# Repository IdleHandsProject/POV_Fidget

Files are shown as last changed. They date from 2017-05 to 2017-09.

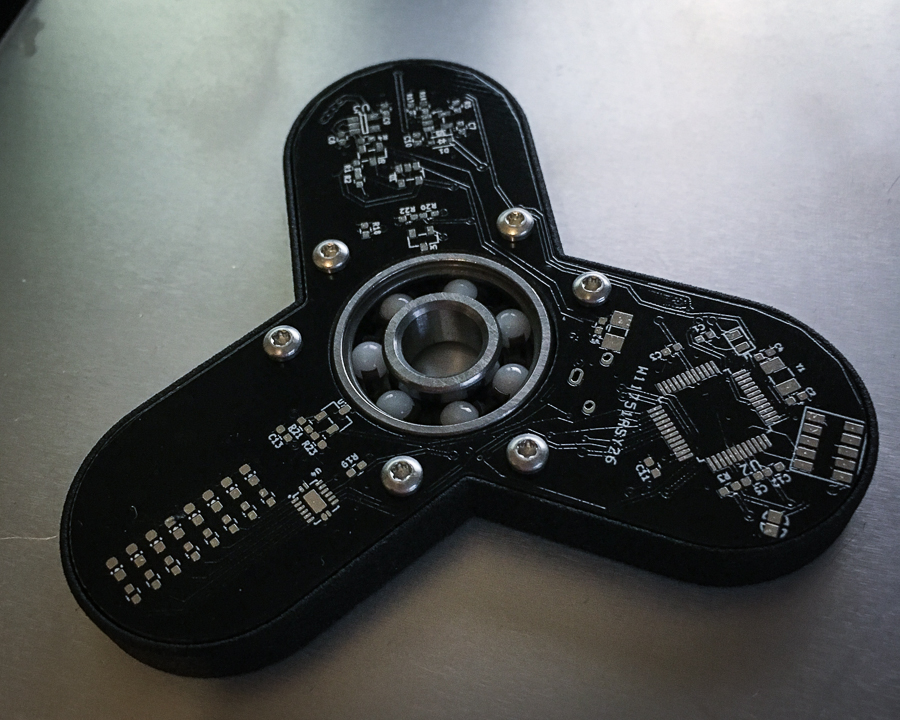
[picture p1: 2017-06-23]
MEDIA/Photo 2017-06-06, 8 44 38 PM.jpg

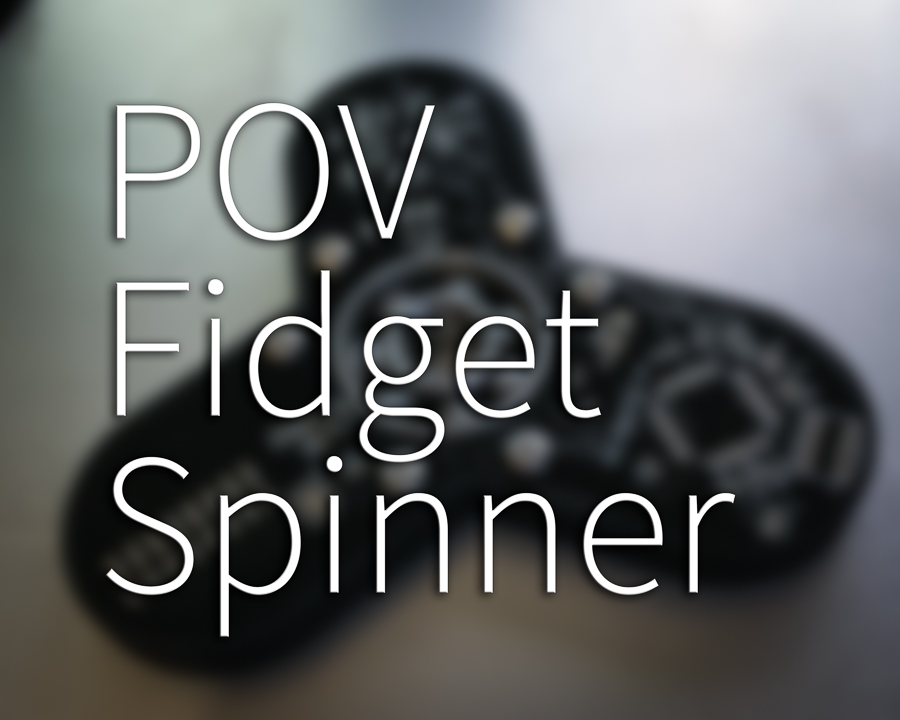
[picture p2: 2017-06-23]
MEDIA/Photo 2017-06-06, 8 44 38 PM-Edit-2.jpg

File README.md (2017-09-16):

# POV Arduino Fidget Spinner!

A lot of the info is in the video, check it out(Click the Image)!

DIY Arduino Fidget Spinner Video (http://www.youtube.com/watch?v=quEMfbOoROQ "Arduino POV Fidget Spinner")

Some more useful links:

https://hackaday.io/project/25538-pov-fidget-spinner

https://www.instructables.com/id/POV-Arduino-Fidget-Spinner/

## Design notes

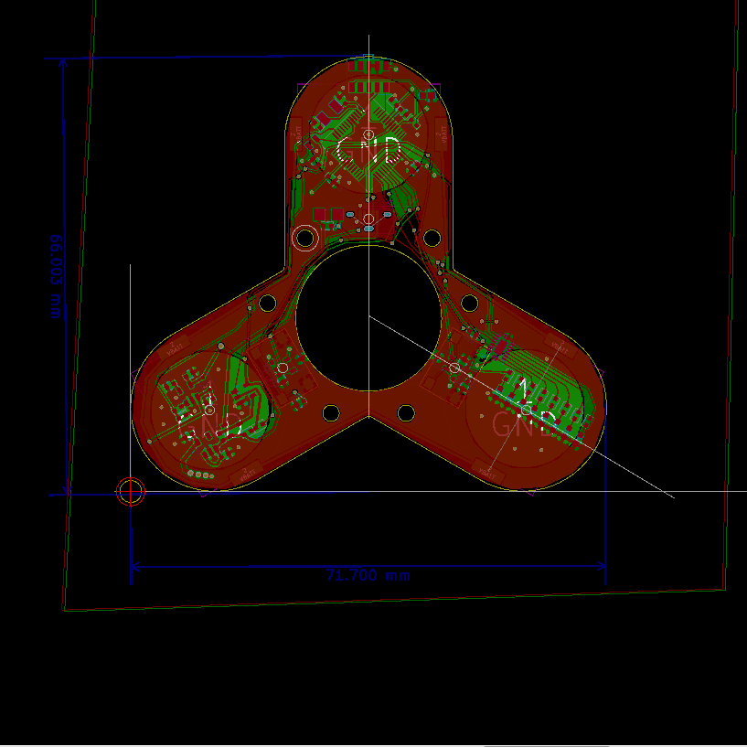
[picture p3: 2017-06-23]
MEDIA/Schem.png

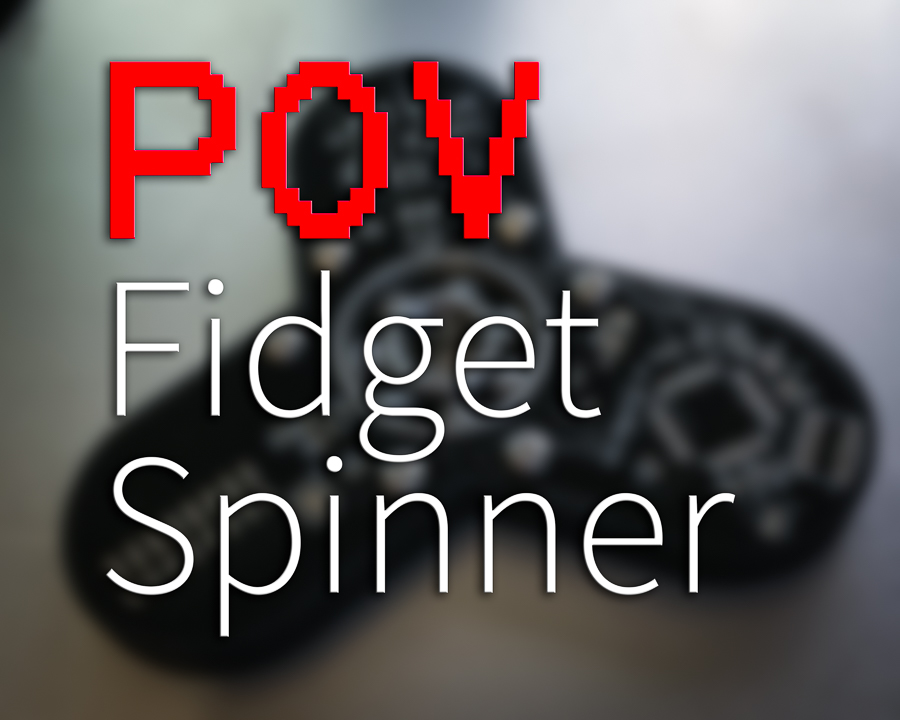
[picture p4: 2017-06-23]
MEDIA/Photo 2017-06-06, 8 44 38 PM-Edit.jpg

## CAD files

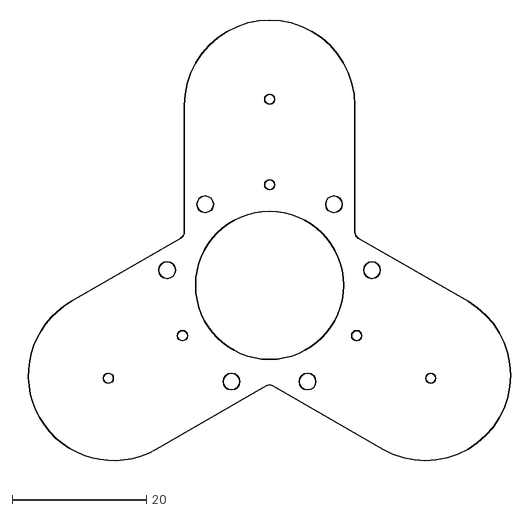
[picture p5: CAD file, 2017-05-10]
CAD/DXF/Body.dxf
73.8 x 68.1

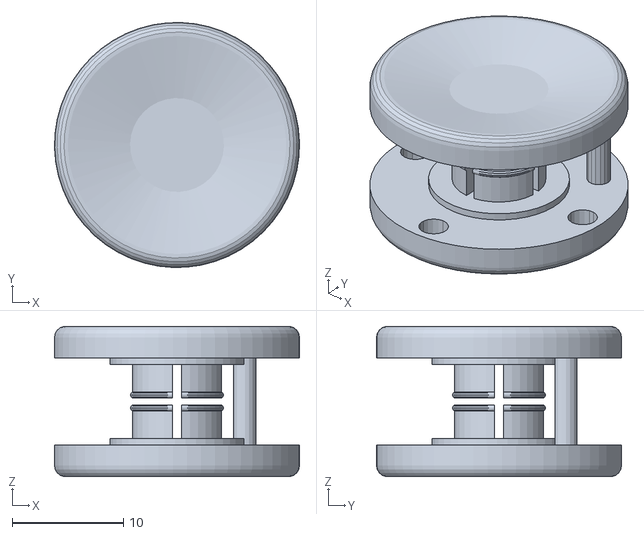
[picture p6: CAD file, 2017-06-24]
CAD/STL/22mm_Cap_Magnet_PairSprue.stl
22.0 x 22.0 x 13.5

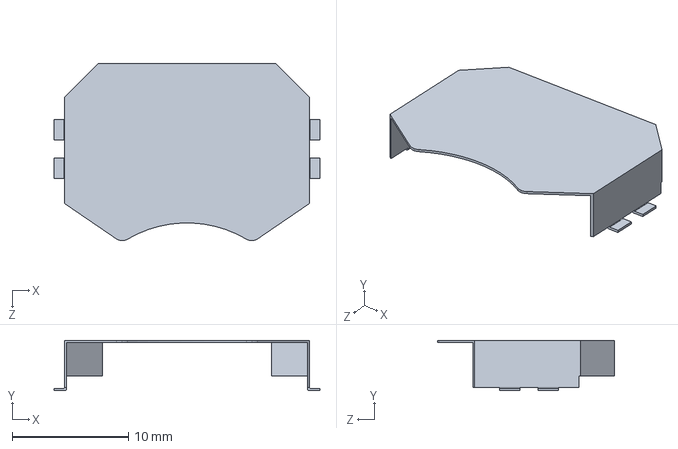
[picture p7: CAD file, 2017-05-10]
CAD/BK-912.STEP
22.9 x 4.32 x 15.2 mm

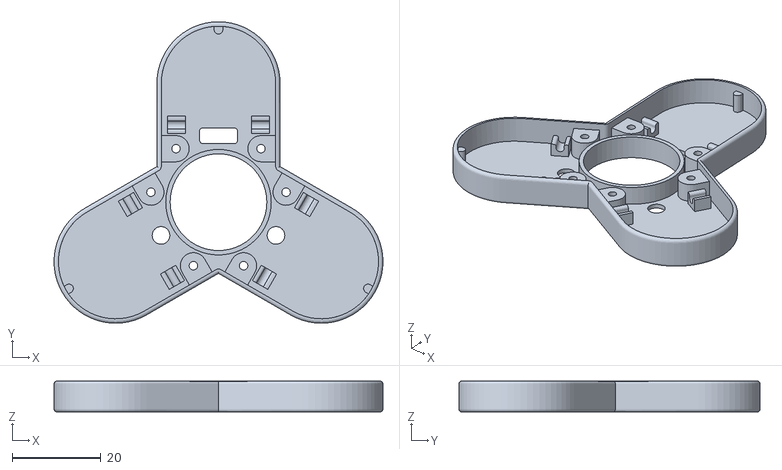
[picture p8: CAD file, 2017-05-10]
CAD/STL/Body_TriSpinArduino.stl
74.4 x 68.1 x 7.00

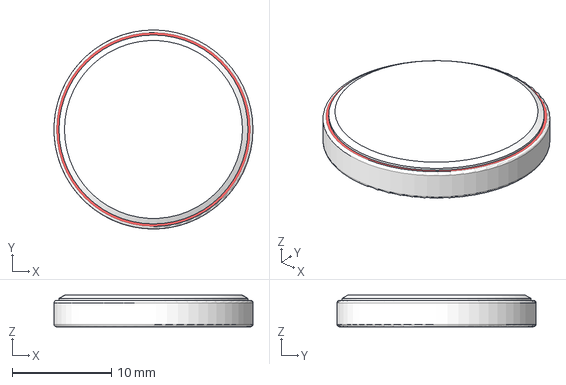
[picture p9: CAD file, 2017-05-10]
CAD/Battery CR2032.stp
20.0 x 20.0 x 3.18 mm

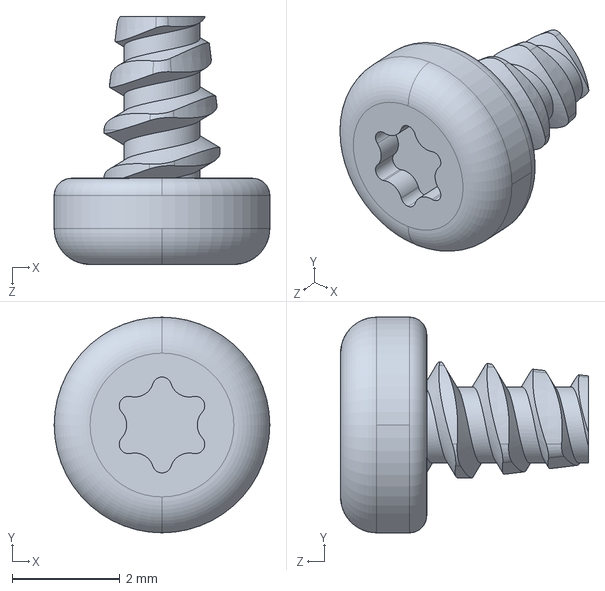
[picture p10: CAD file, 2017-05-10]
CAD/99397A321_METRIC THREAD-FORMING SCREW FOR PLASTICS.STEP
4.00 x 4.00 x 4.60 mm

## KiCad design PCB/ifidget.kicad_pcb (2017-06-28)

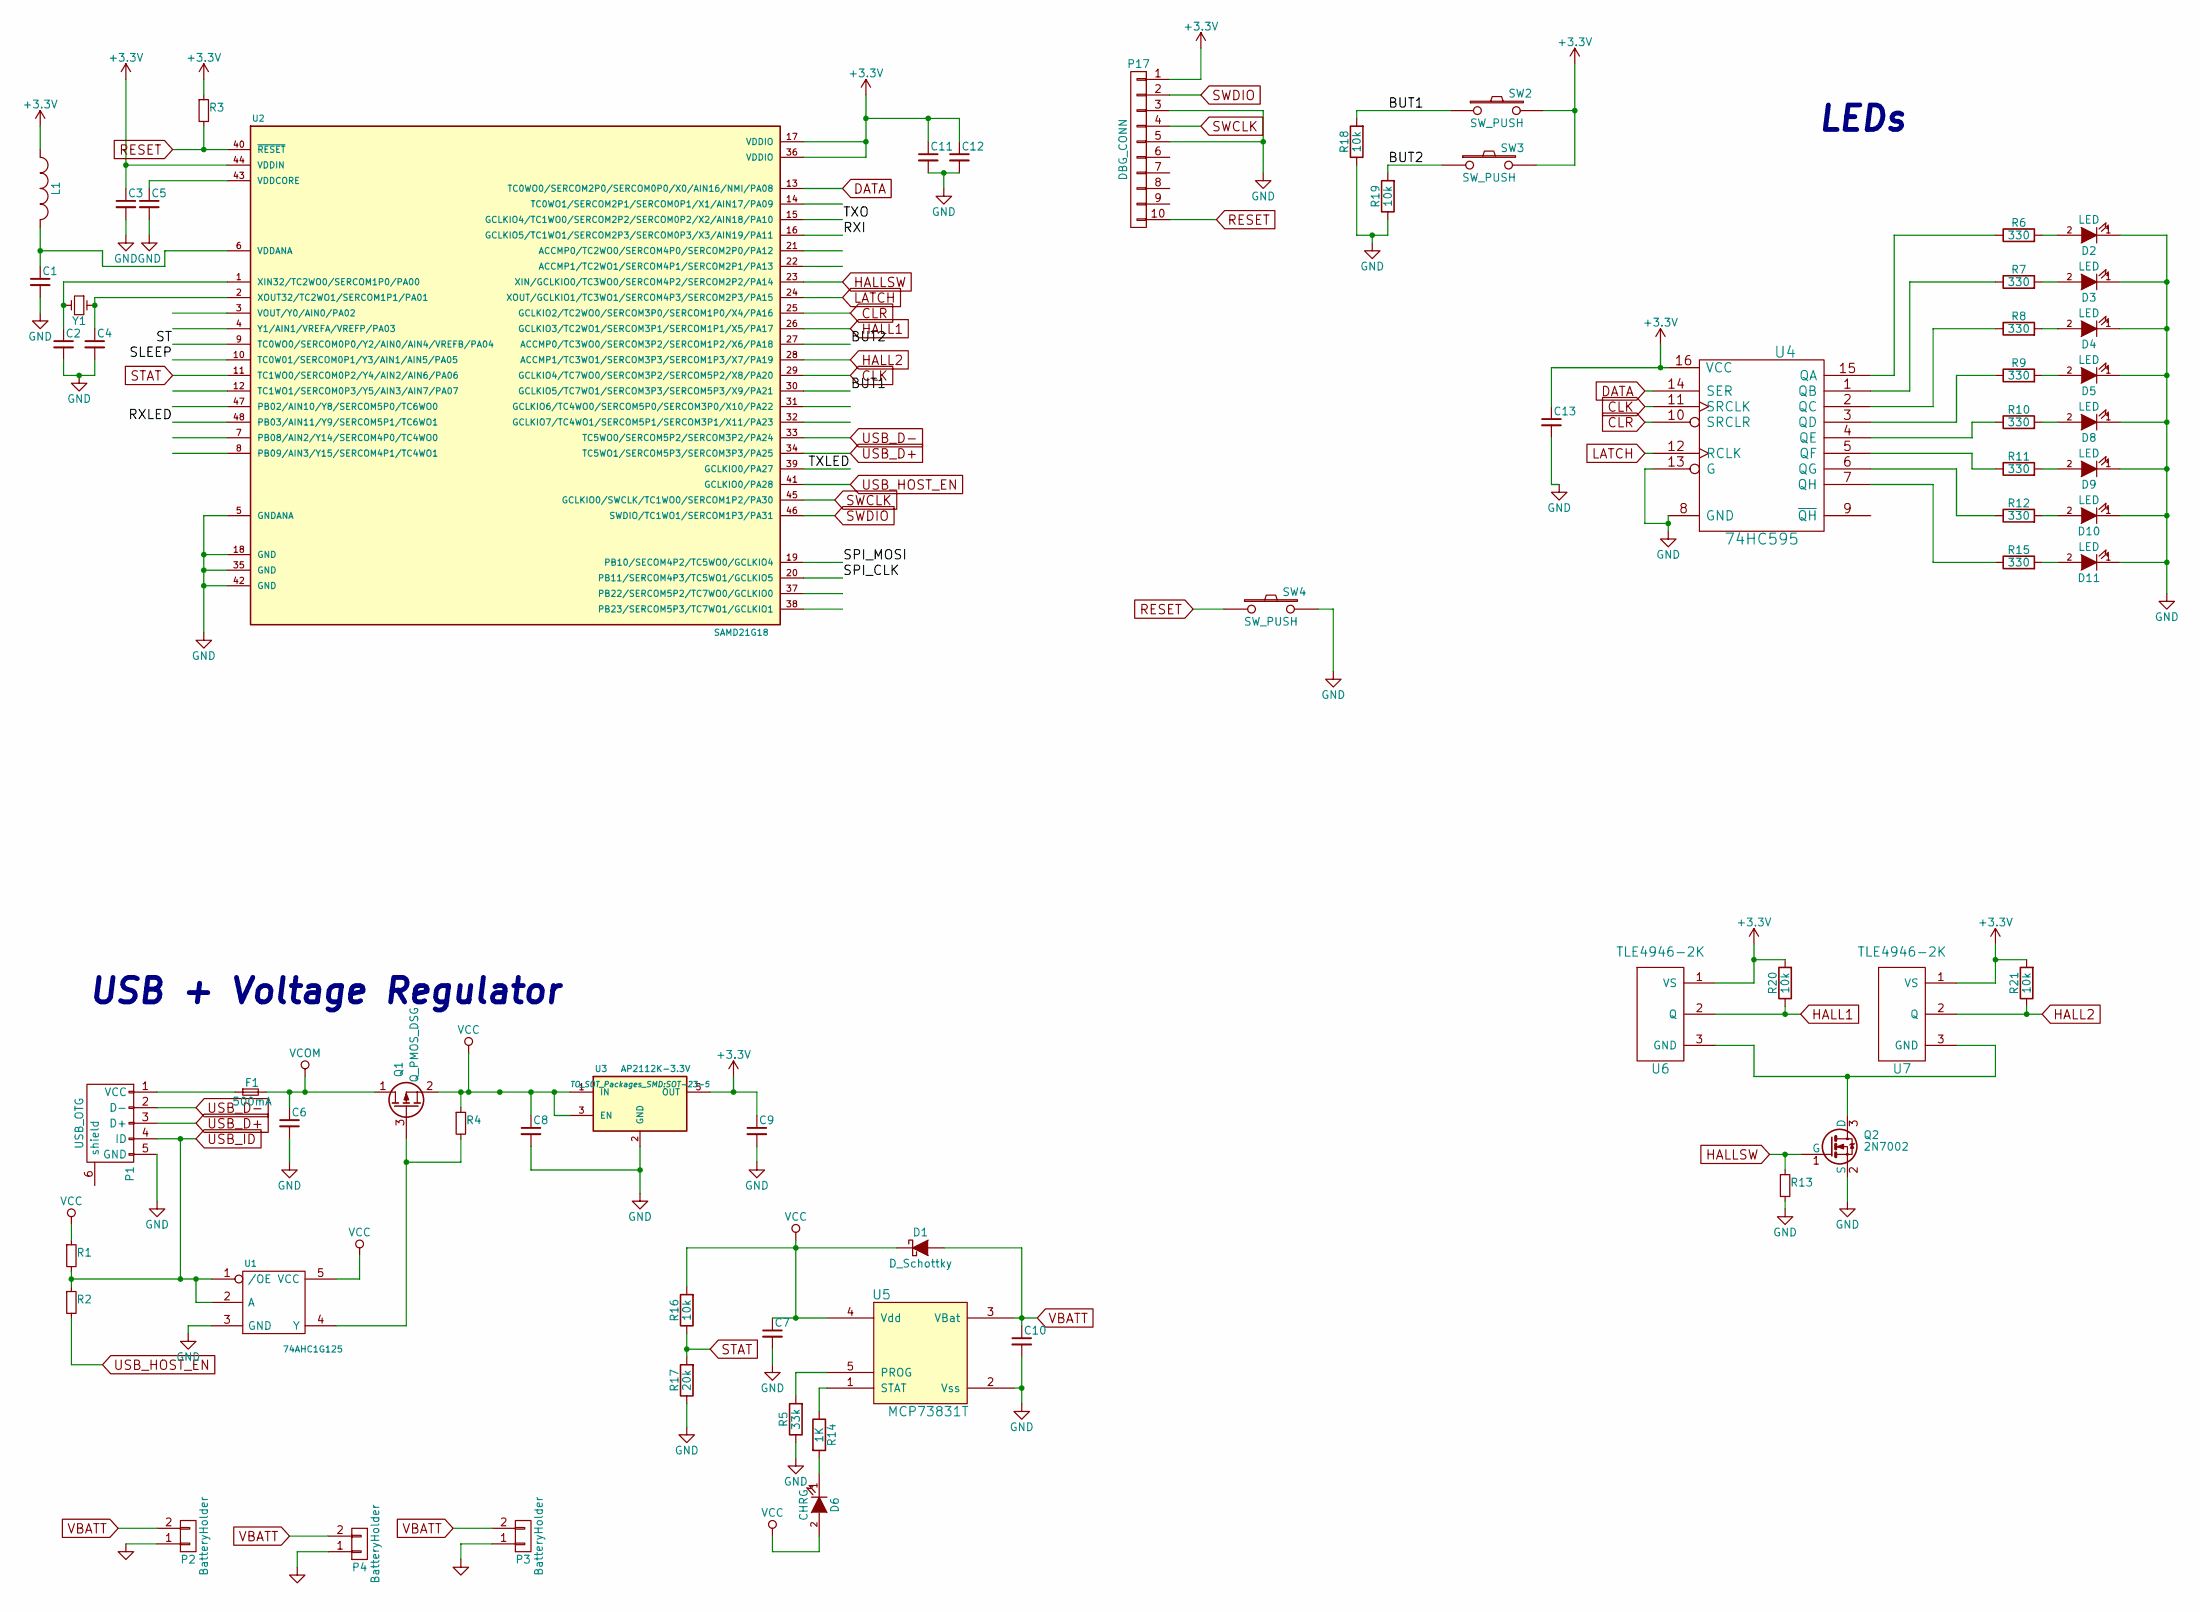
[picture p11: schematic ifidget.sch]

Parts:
C1, C3, C5, C11, C12: 0.1uF; C_0402_Hand; Digikey Part No. 490-6328-1-ND
C2, C4: 15pF; C_0402_Hand; Digikey Part No. 712-1261-1-ND
C6: 2.2uF; C_0402_Hand; Digikey Part No. 1276-1291-1-ND
C7, C10: 4.7uF; C_0402_Hand; Digikey Part No. 490-5915-1-ND
C8, C13: 1uF; C_0402_Hand; Digikey Part No. 490-4516-1-ND
C9: 2.2uF; C_0402_Hand; Digikey Part No. 1276-1469-1-ND
D1: D_Schottky; sod80c; Digikey Part No. 497-3381-1-ND
D2, D3, D4, D5, D8, D9, D10, D11: LED; Led_0603; Digikey Part No. 160-1436-1-ND
D6: CHRG; Led_0603; Digikey Part No. 160-1436-1-ND
F1: 500mA; c_1206; Digikey Part No. 507-1803-1-ND
L1: FB - 30Ohm; R_SM0603; Digikey Part No. 445-2986-1-ND
P1: USB_OTG; USB_Micro-B_VERT; Digikey Part No. WM9734CT-ND
P2, P3, P4: BatteryHolder; CoinCellHolder_TH; Digikey Part No. BK-912-G-CT-ND
P17: DBG_CONN; Pin_Header_Straight_2x05_Pitch1.27mm; Digikey Part No. 1175-1627-ND
Q1: Q_PMOS_DSG; SOT23; Digikey Part No. DMG2307L-7DICT-ND
Q2: 2N7002; SOT-23; Digikey Part No. 1727-4793-1-ND
R1, R13: 100k; R_0402_Hand; Digikey Part No. 311-100KLRCT-ND
R2, R6, R7, R8, R9, R10, R11, R12, R15: 330; R_0402_Hand; Digikey Part No. 311-330JRCT-ND
R3, R16, R18, R19, R20, R21: 10k; R_0402_Hand; Digikey Part No. 311-10KJRCT-ND
R4: 47K; R_0402_Hand; Digikey Part No. 311-47.0KLRCT-ND
R5: 33k; R_0402_Hand; Digikey Part No. 311-33KJRCT-ND
R14: 1K; R_0402_Hand; Digikey Part No. 311-1.0KJRCT-ND
R17: 20k; R_0402_Hand; Digikey Part No. 311-20KJRCT-ND
SW2, SW3: SW_PUSH; SW_SPST_PTS645; Digikey Part No. CKN9112CT-ND
SW4: SW_PUSH; SOLDER-JUMPER_1-WAY; Digikey Part No. CKN9084CT-ND
U1: 74AHC1G125; sot23-5; Digikey Part No. 1727-6024-1-ND
U2: SAMD21G18; TQFP-48_7x7mm_Pitch0.5mm; Digikey Part No. ATSAMD21G18A-AU-ND
U3: AP2112K-3.3V; SOT-23-5; Digikey Part No. AP2112K-3.3TRG1DICT-ND
U4: 74HC595; pvqfn-n16; Digikey Part No. 1727-3327-1-ND
U5: MCP73831T; sot23-5; Digikey Part No. MCP73831T-2ACI/OTCT-ND
U6, U7: TLE4946-2K; SOT23; Digikey Part No. TLE49462KHTSA1CT-ND
Y1: Crystal_Small; crystal_smd_5x3.2mm; Digikey Part No. XC1617CT-ND

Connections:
+3V3: C3.1, C9.1, C11.1, C12.1, C13.1, L1.1, P17.1, R3.1, R20.2, R21.2, SW2.2, SW3.2, U2.17 (VDDIO), U2.36 (VDDIO), U2.44 (VDDIN), U3.5 (OUT), U4.16 (VCC), U6.1 (VS), U7.1 (VS)
/BUT1: R18.2, SW2.1, U2.30 (GCLKIO5/TC7WO1/SERCOM3P3/SERCOM5P3/X9/P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)
/BUT2: R19.2, SW3.1, U2.27 (ACCMP0/TC3WO0/SERCOM3P2/SERCOM1P2/X6/PA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)
/RXI: U2.16 (GCLKIO5/TC1WO1/SERCOM2P3/SERCOM0P3/X3/A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)
/RXLED: U2.48 (PB03/AIN11/Y9/SERCOM5P1/TC6WO1)
/SLEEP: U2.10 (TC0W01/SERCOM0P1/Y3/AIN1/AIN5/PA05)
/SPI_CLK: U2.20 (PB11/SERCOM4P3/TC5WO1/GCLKIO5)
/SPI_MOSI: U2.19 (PB10/SECOM4P2/TC5WO0/GCLKIO4)
/ST: U2.9 (TC0WO0/SERCOM0P0/Y2/AIN0/AIN4/VREFB/PA04)
/TXLED: U2.39 (GCLKIO0/PA27)
/TXO: U2.15 (GCLKIO4/TC1WO0/SERCOM2P2/SERCOM0P2/X2/A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)
CLK: U2.29 (GCLKIO4/TC7WO0/SERCOM3P2/SERCOM5P2/X8/P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), U4.11 (SRCLK)
CLR: U2.25 (GCLKIO2/TC2WO0/SERCOM3P0/SERCOM1P0/X4/P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), U4.10 (SRCLR)
DATA: U2.13 (TC0WO0/SERCOM2P0/SERCOM0P0/X0/AIN16/NMI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), U4.14 (SER)
GND: C1.2, C2.2, C3.2, C4.2, C5.2, C6.2, C7.2, C8.2, C9.2, C10.2, C11.2, C12.2, C13.2, D2.1 (K), D3.1 (K), D4.1 (K), D5.1 (K), D8.1 (K), D9.1 (K), D10.1 (K), D11.1 (K), P1.5 (GND), P2.1, P3.1, P4.1, P17.3, P17.5, Q2.2 (S), R5.1, R13.2, R17.1, R18.1, R19.1, SW4.2, U1.3 (GND), U2.5 (GNDANA), U2.18 (GND), U2.35 (GND), U2.42 (GND), U3.2 (GND), U4.8 (GND), U4.13 (G), U5.2 (Vss); also elsewhere on the board
HALL1: R20.1, U2.26 (GCLKIO3/TC2WO1/SERCOM3P1/SERCOM1P1/X5/P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), U6.2 (Q); also elsewhere on the board
HALL2: R21.1, U2.28 (ACCMP1/TC3WO1/SERCOM3P3/SERCOM1P3/X7/PA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), U7.2 (Q); also elsewhere on the board
HALLSW: Q2.1 (G), R13.1, U2.23 (XIN/GCLKIO0/TC3WO0/SERCOM4P2/SERCOM2P2/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)
LATCH: U2.24 (XOUT/GCLKIO1/TC3WO1/SERCOM4P3/SERCOM2P3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), U4.12 (RCLK)
unnamed: C1.1, L1.2, U2.6 (VDDANA)
unnamed: C2.1, U2.1 (XIN32/TC2WO0/SERCOM1P0/PA00), Y1.2
unnamed: C4.1, U2.2 (XOUT32/TC2WO1/SERCOM1P1/PA01), Y1.1
unnamed: C5.1, U2.43 (VDDCORE)
unnamed: D2.2 (A), R6.2
unnamed: D3.2 (A), R7.2
unnamed: D4.2 (A), R8.2
unnamed: D5.2 (A), R9.2
unnamed: D6.1 (K), R14.2
unnamed: D8.2 (A), R10.2
unnamed: D9.2 (A), R11.2
unnamed: D10.2 (A), R12.2
unnamed: D11.2 (A), R15.2
unnamed: F1.1, P1.1 (VCC)
unnamed: Q1.3 (G), R4.2, U1.4 (Y)
unnamed: Q2.3 (D), U6.3 (GND), U7.3 (GND)
unnamed: R5.2, U5.5 (PROG)
unnamed: R6.1, U4.15 (QA)
unnamed: R7.1, U4.1 (QB)
unnamed: R8.1, U4.2 (QC)
unnamed: R9.1, U4.3 (QD)
unnamed: R10.1, U4.4 (QE)
unnamed: R11.1, U4.5 (QF)
unnamed: R12.1, U4.6 (QG)
unnamed: R14.1, U5.1 (STAT)
unnamed: R15.1, U4.7 (QH)
RESET: P17.10, R3.2, SW4.1, U2.40 (~RESET~)
STAT: R16.1, R17.2, U2.11 (TC1WO0/SERCOM0P2/Y4/AIN2/AIN6/PA06)
SWCLK: P17.4, U2.45 (GCLKIO0/SWCLK/TC1WO0/SERCOM1P2/PA30)
SWDIO: P17.2, U2.46 (SWDIO/TC1WO1/SERCOM1P3/PA31)
USB_D+: P1.3 (D+), U2.34 (TC5WO1/SERCOM5P3/SERCOM3P3/PA25)
USB_D-: P1.2 (D-), U2.33 (TC5WO0/SERCOM5P2/SERCOM3P2/PA24)
USB_HOST_EN: R2.2, U2.41 (GCLKIO0/PA28)
USB_ID: P1.4 (ID), R1.2, R2.1, U1.1 (/OE), U1.2 (A)
VBATT: C10.1, D1.2 (A), P2.2, P3.2, P4.2, U5.3 (VBat)
VCC: C7.1, C8.1, D1.1 (K), D6.2 (A), Q1.2 (S), R1.1, R4.1, R16.2, U1.5 (VCC), U3.1 (IN), U3.3 (EN), U5.4 (Vdd)
VCOM: C6.1, F1.2, Q1.1 (D)

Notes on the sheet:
USB + Voltage Regulator
LEDs

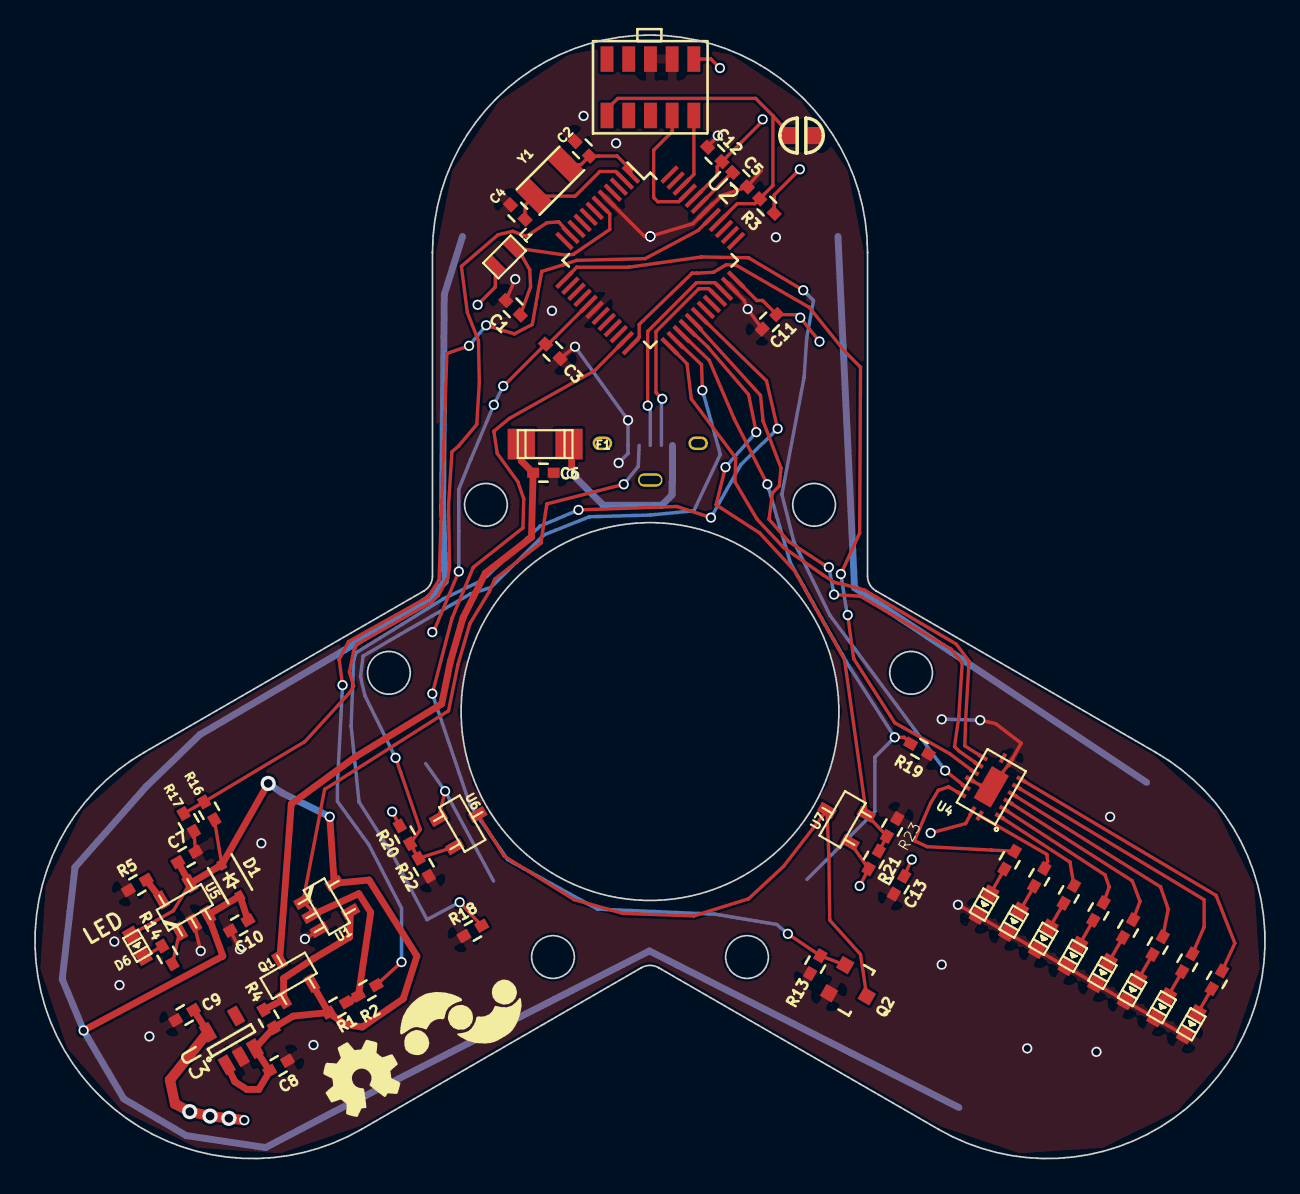
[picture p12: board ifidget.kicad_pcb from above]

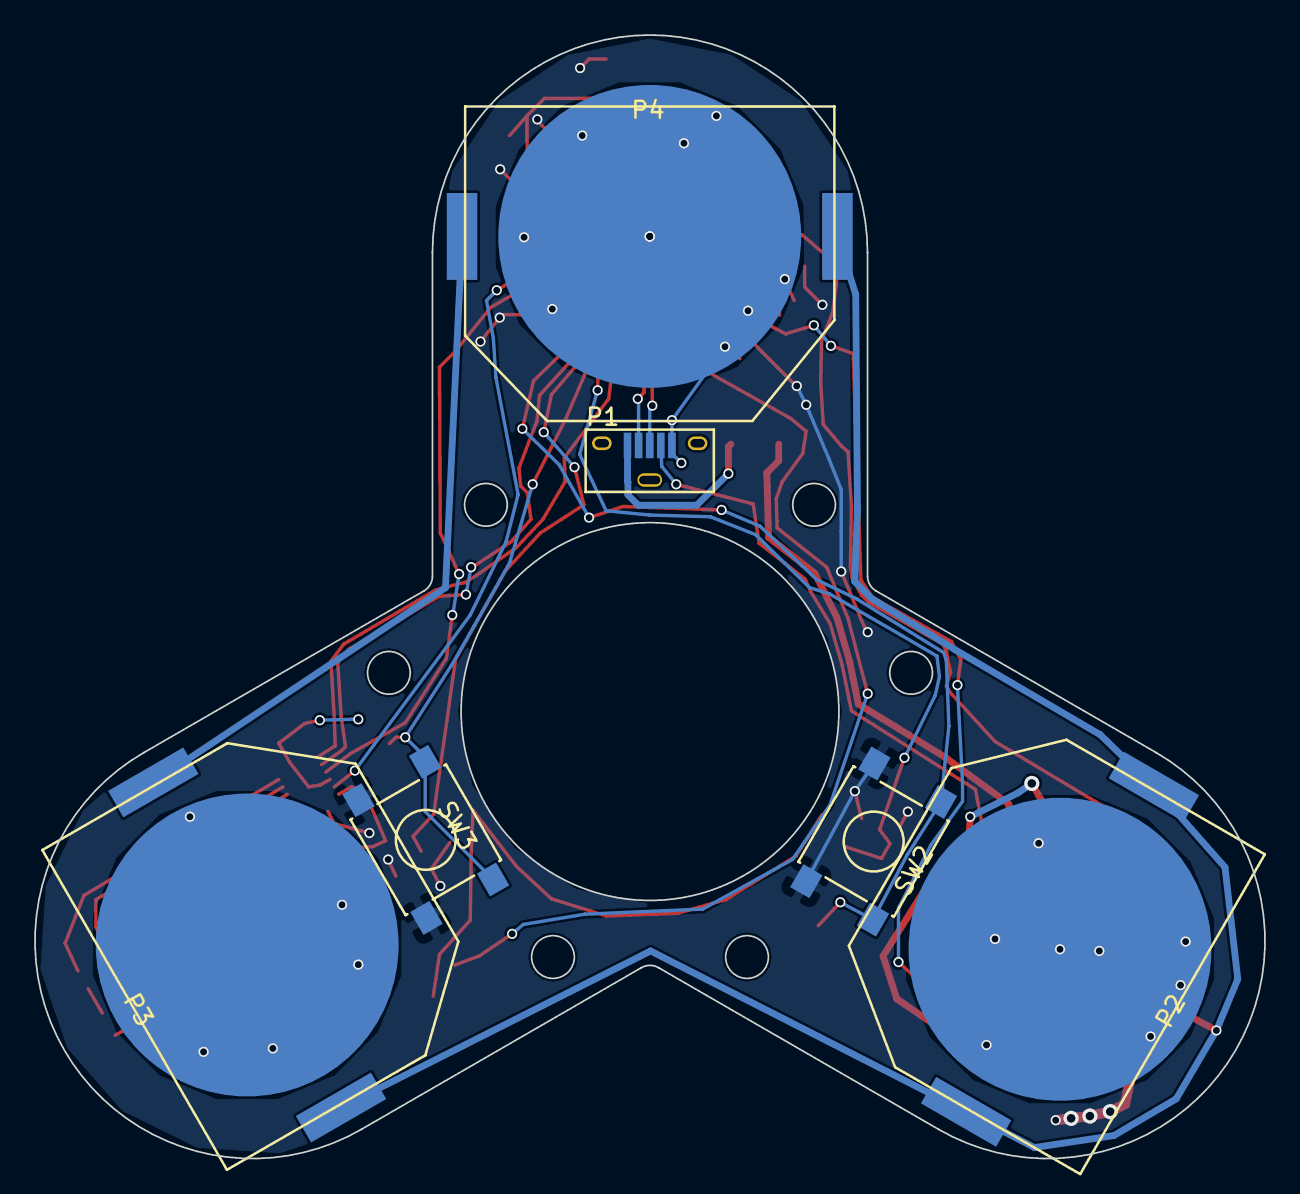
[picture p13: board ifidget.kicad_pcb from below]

Board: 2 copper layers, 71.9 x 65.7 mm, 66 parts (6 on the bottom side), 48 nets.

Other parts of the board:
R22, R23: 10k; R_0402_Hand

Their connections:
GND: R22.1, R23.1; also elsewhere on the board
HALL1: R22.2; also elsewhere on the board
HALL2: R23.2; also elsewhere on the board

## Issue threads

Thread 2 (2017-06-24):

Add reverse voltage diodes for batteries

hodginsa, 2017-06-24:
Probably a good idea for some voltage protection.

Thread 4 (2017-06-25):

DNP R16/R17

hodginsa, 2017-06-25:
Do not Populate R16/R17.
They do not allow the LiPo chip to charge the battery. Will add a voltage divider on the 5V line to the MCu to know when it is plugged in, instead of the "Charge state" led.

hodginsa, 2017-06-28:
Fixed, Populating allows analog voltage read of batt/charger.

Closed 2017-06-28.

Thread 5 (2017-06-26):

Fix Recessed buttons

hodginsa, 2017-06-26:
The buttons are too recessed to reach without a screwdriving(or anything pointy). Come up with solution to avoid this.

Note to self: add bendy pieces to 3D printed body as "buttons". Should work well.

hodginsa, 2017-06-28:
Fixed Body.

Closed 2017-06-28.

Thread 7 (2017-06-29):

Schematic file format?

ArcAIN6, 2017-06-29:
Just tried to open the PCB sch file, and alas, it doesn't open in Eagle 7.6. Could you please let us know what software you're using?

hodginsa, 2017-06-29:
Its KICAD my friend.

Devil4492, 2017-06-30:
Thanks mate :)

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

Devil4492, 2017-06-30:
But I pulled the requested by mistakenly maybe.

On 30-Jun-2017 10:02 AM, "Rushikesh Palkar" <rushikesh.palkar99@gmail.com>
wrote:

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

ArcAIN6, 2017-06-30:
Tyvm :)

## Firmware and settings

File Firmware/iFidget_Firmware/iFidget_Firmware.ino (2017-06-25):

//**************************************************************//
//  Name    : iFidget Firmware
//  Author  : Sean Hodgins
//  Date    : 23/06/2017
//  Notes: Firmware for the POV Fidget Spinner
//  https://github.com/IdleHandsProject/POV_Fidget
//  https://hackaday.io/project/25538-pov-fidget-spinner
//****************************************************************
#include <Arduino.h>

#include "font.h"
#include "ZeroEEPROM.h"
#include "LowPower.h"

int latchPin = 5;
int clockPin = 6;
int dataPin = 4;
int clr = 11;
int chargePin = 8;

#define BUTT1 7
#define BUTT2 10
#define BENC1 13
#define BENC2 12

byte flag1 = 0;
byte flag2 = 0;
int encoderValueB = 0;
int lastEncodedB = 0;
int newB = 0;
int sum = 0;
byte flagB = 0;
byte state1 = 0;
byte state2 = 0;

unsigned int starttime = 0;
unsigned int stoptime = 0;
unsigned int RPM = 0;
unsigned int SpinCount = 0;

byte currentMenu = 0x01;
int menuFlag = 0;
int sleepFlag = 0;
int wakeFlag = 0;

// output tracking vars
int  iWrdIndex;
int  iMsgIndex;
int  iCharIndex;
int  iCharLen;
int wordChange = 0;
int wordWrite = 1;


void setup() {
  //set pins to output so you can control the shift register
  pinMode(latchPin, OUTPUT);
  pinMode(clockPin, OUTPUT);
  pinMode(dataPin, OUTPUT);
  pinMode(BENC1, INPUT);
  pinMode(BENC2, INPUT);
  pinMode(BUTT1, INPUT);
  pinMode(BUTT2, INPUT);
  attachInterrupt(BENC1, trig1, CHANGE);
  //attachInterrupt(BENC2, trig2, CHANGE);
  attachInterrupt(BUTT1, WakeUpEmpty, HIGH);
  attachInterrupt(BUTT2, menuChange, RISING);
  SerialUSB.begin(115200);
  digitalWrite(clr, HIGH);

  /////LOW POWER MODE//////
  //pinMode(6, INPUT_PULLUP);
  pinMode(chargePin, INPUT);
  pinMode(3, INPUT_PULLUP);
  pinMode(2, INPUT_PULLUP);
  pinMode(1, INPUT_PULLUP);
  pinMode(0, INPUT_PULLUP);
  pinMode(A5, INPUT_PULLUP);
  pinMode(A4, INPUT_PULLUP);
  pinMode(A3, INPUT_PULLUP);
  pinMode(A2, INPUT_PULLUP);
  pinMode(A1, INPUT_PULLUP);
  pinMode(A0, INPUT_PULLUP);
  //pinMode(13, INPUT_PULLUP);
  pinMode(38, INPUT_PULLUP);
  pinMode(30, INPUT_PULLUP);
  pinMode(31, INPUT_PULLUP);


  sendByteOut(currentMenu);
  delay(500);
  sendByteOut(0x00);
}

void sendByteOut(int value) {
  digitalWrite(latchPin, LOW);                     // set the strobe LOW
  shiftOut(dataPin, clockPin, LSBFIRST, value);
  digitalWrite(latchPin, HIGH);
  delayMicroseconds(100);
  digitalWrite(latchPin, LOW);

}

void sendCharOut(int character, int row) {
  digitalWrite(latchPin, LOW);                     // set the strobe LOW
  shiftOut(dataPin, clockPin, LSBFIRST, font[character - 32][row]);
  digitalWrite(latchPin, HIGH);
  delayMicroseconds(100);
  digitalWrite(latchPin, LOW);

}

void displayChar(int character) {
  for (int x = 0; x < 2; x++) {
    sendCharOut(' ', x);
    delay(1);
  }
  for (int x = 0; x < 5; x++) {
    sendCharOut(character, x);
    delay(1);
  }
  for (int x = 0; x < 2; x++) {
    sendCharOut(' ', x);
    delay(1);
  }
}

void displayWord(String input) {
  char buff[12];
  input.toCharArray(buff, 12);
  int stringlength = input.length();
  for (int x = 0; x < stringlength; x++) {
    displayChar(buff[x]);
  }
}

void loop() {

  int chargeState = digitalRead(chargePin);
  byte chargeLEDs = 0;
  byte dir = 0;
  while (chargeState == HIGH) {
    chargeState = digitalRead(chargePin);

    sendByteOut(chargeLEDs);

    if (chargeLEDs > 0x80) {
      dir = 1;
    }
    if (chargeLEDs <= 0) {
      dir = 0;
    }
    if (dir == 0) {
      chargeLEDs = chargeLEDs  << 1;
    }
    else {
      chargeLEDs =  chargeLEDs >> 1;
    }
    delay(100);
  }


  if (sleepFlag == 1) {
    digitalWrite(clr, LOW);
    goingtoSleep();
  }
  sleepFlag = 0;
  if (wakeFlag == 1) {
    byte ledstate = 1;
    //attachInterrupt(BUTT1, WakeUpEmpty, HIGH);
    for (int x = 0; x < 15; x++) {
      sendByteOut(ledstate);
      ledstate = ledstate << 1;
      if (ledstate > 0x80) {
        ledstate = ledstate >> 1;
      }
      if (ledstate == 0) {
        ledstate = 0x01;
      }
      delay(10);
    }
    sendByteOut(0x00);
    wakeFlag = 0;
  }

  if (menuFlag == 1) {
    starttime = millis();
    sendByteOut(currentMenu);
    int butt2State = digitalRead(BUTT2);
    int startTime = millis();
    int menuTime = 0;
    while (butt2State == HIGH && menuTime < 1000) {
      int menuWait = millis();
      menuTime = menuWait - startTime;
      butt2State = digitalRead(BUTT2);
    }
    if (butt2State == HIGH) {
      if (currentMenu <= 0x80) {
        currentMenu = currentMenu << 1;
      }
      if (currentMenu == 0) {
        currentMenu = currentMenu + 1;
      }
    }
    sendByteOut(currentMenu);
    delay(500);
    sendByteOut(0x00);
    menuFlag = 0;
  }

  String SRPM = "";

  if (flag1 == 1) {

    starttime = millis();
    unsigned int difTime = starttime - stoptime;
    RPM = difTime * 2;
    RPM = 60000 / RPM;
    SRPM = String(RPM);
    stoptime = starttime;


    if (currentMenu == 0x01) {
      displayWord(SRPM);
    }

    if (currentMenu == 0x02) {
      if (wordChange < 20) {
        displayWord("HELLO");
      }
      if (20 < wordChange && wordChange < 40) {
        displayWord("WORLD");
      }
      wordChange++;
      if (wordChange > 40) {
        wordChange = 0;
      }

    }

    if (currentMenu == 0x04) {
      String SCOUNT = String(SpinCount);
      //SerialUSB.println(SCOUNT);
      displayWord(SCOUNT);
    }

    if (currentMenu == 0x08) {
      if (wordChange < 10) {
        displayWord("DIY");
      }
      if (10 < wordChange && wordChange < 20) {
        displayWord("ARDUINO");
      }
      if (20 < wordChange && wordChange < 30) {
        displayWord("FIDGET");
      }
      if (30 < wordChange && wordChange < 40) {
        displayWord("SPINNER");
      }
      wordChange++;
      if (wordChange > 40) {
        wordChange = 0;
      }
    }

    if (currentMenu == 0x10) {
      if (wordChange < 10) {
        displayWord("POV");
      }
      if (10 < wordChange && wordChange < 20) {
        displayWord("ARDUINO");
      }
      if (20 < wordChange && wordChange < 30) {
        displayWord("FIDGET");
      }
      if (30 < wordChange && wordChange < 40) {
        displayWord("SPINNER");
      }
      wordChange++;
      if (wordChange > 40) {
        wordChange = 0;
      }
    }
    if (currentMenu == 0x20) {
      if (wordChange < 10) {
        displayWord("HELLO");
      }
      if (10 < wordChange && wordChange < 20) {
        displayWord("WORLD");
      }
      if (20 < wordChange && wordChange < 30) {
        displayWord("AND");
      }
      if (30 < wordChange && wordChange < 40) {
        displayWord("HaD :)");
      }
      wordChange++;
      if (wordChange > 40) {
        wordChange = 0;
      }
    }
if (currentMenu == 0x40) {
      if (wordChange < 10) {
        displayWord("HELLO");
      }
      if (10 < wordChange && wordChange < 20) {
        displayWord("REDDIT!");
      }
      if (20 < wordChange && wordChange < 25) {
        displayWord("THIS");
      }
      if (25 < wordChange && wordChange < 30) {
        displayWord("IS");
      }
      if (30 < wordChange && wordChange < 35) {
        displayWord("MY");
      }
      if (35 < wordChange && wordChange < 45) {
        displayWord("POV");
      }
      if (45 < wordChange && wordChange < 55) {
        displayWord("FIDGET");
      }
      if (55 < wordChange && wordChange < 70) {
        displayWord("SPINNER");
      }
      if (70 < wordChange && wordChange < 75) {
        displayWord("   ");
      }
      if (75 < wordChange && wordChange < 80) {
        displayWord("SEND");
      }
      if (80 < wordChange && wordChange < 85) {
        displayWord("NUDES");
      }
      
      wordChange++;
      if (wordChange > 85) {
        wordChange = 0;
      }
    }


    int stretchDelay = 500;
    if (RPM < 1000) {

      stretchDelay = 1000 - RPM;
    }
    delayMicroseconds(stretchDelay);
    flag1 = 0;
  }
  int timeoutSleeptime = millis();
  unsigned long timeoutInt = 25000;
  unsigned long timeoutSleep = timeoutSleeptime - starttime;
  byte pluggedIn = 0;
  pluggedIn = digitalRead(chargePin);
  if (timeoutSleep > timeoutInt) {
    byte ledstate = 1;
    //attachInterrupt(BUTT1, WakeUpEmpty, HIGH);
    for (int x = 0; x < 15; x++) {
      sendByteOut(ledstate);
      ledstate = ledstate << 1;
      if (ledstate > 0x80) {
        ledstate = ledstate >> 1;
      }
      if (ledstate == 0) {
        ledstate = 0x01;
      }
      delay(10);
    }
    sendByteOut(0x00);
    delay(50);
    USBDevice.detach();
    LowPower.standby();
  }
}


void updateEncoderB() {
  int MSB = digitalRead(BENC1); //MSB = most significant bit
  int LSB = digitalRead(BENC2); //LSB = least significant bit

  int encoded = (MSB << 1) | LSB; //converting the 2 pin value to single number
  sum  = (lastEncodedB << 2) | encoded; //adding it to the previous encoded value

  if (sum == 0b0010 || sum == 0b1101 || sum == 0b1011 || sum == 0b0100) encoderValueB ++;
  if (sum == 0b1110 || sum == 0b1000 || sum == 0b0001 || sum == 0b0111) encoderValueB --;

  lastEncodedB = encoded; //store this value for next time
  flagB = 1;
}

int Lstate1 = 0;
int Lstate2 = 0;

void trig1() {
  state1 = digitalRead(BENC1);
  state2 = digitalRead(BENC2);
  if (state1 == 1 && state2 == 1) {
    flag1 = 1;
    SpinCount++;
    int Lstate1 = state1;
    int Lstate2 = state2;
  }
}

void trig2() {
  state2 = digitalRead(BENC2);
  flag2 = 1;
}


void sleepTime() {
  sleepFlag = 1;

}

void goingtoSleep() {
  unsigned long pM = 0;
  const long interval = 100;
  int butt1State = digitalRead(BUTT1);
  int startTime = millis();
  int menuTime = 0;
  byte ledstate = 1;
  while (butt1State == HIGH && menuTime < 4000) {
    int menuWait = millis();
    menuTime = menuWait - startTime;
    butt1State = digitalRead(BUTT1);

    unsigned long cM = millis();
    if (cM - pM >= interval) {
      // save the last time you blinked the LED
      pM = cM;

      sendByteOut(ledstate);
      ledstate = ledstate << 1;
      if (ledstate > 0x80) {
        ledstate = ledstate >> 1;
      }
      if (ledstate == 0) {
        ledstate = 0x01;
      }
    }
  }
  sendByteOut(0x00);
  if (butt1State == HIGH) {

    delay(50);
    detachInterrupt(BENC1);
    detachInterrupt(BENC2);
    //detachInterrupt(BUTT2);
    detachInterrupt(BUTT1);
    attachInterrupt(BUTT1, WakeUp, RISING);
    delay(50);
    USBDevice.detach();
    LowPower.standby();
    detachInterrupt(BUTT1);
    pinMode(BUTT1, OUTPUT);
    delay(10);
    pinMode(BUTT1, INPUT);
  }

}

void menuChange() {
  menuFlag = 1;
}

void WakeUp() {
  wakeFlag = 1;
  USBDevice.attach();
}

void WakeUpEmpty() {
  USBDevice.attach();
  starttime = millis();
  wakeFlag = 1;
}

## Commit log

2017-06-24 Removed some parts, added STLs
    [22mm_Cap_Magnet.CATPart, 22mm_Cap_Magnet_PairSprue.stl, Arduino Spinner.CATProduct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]
2017-06-24 fixed Q1 Pads
    [ifidget-B.Cu.gbr, ifidget-B.Mask.gbr, ifidget-B.SilkS.gbr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]
2017-06-28 fixes to power and listed issues
    [ifidget-B.Cu.gbr, ifidget-B.Mask.gbr, ifidget-B.SilkS.gbr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]
2017-06-28 Small fix
    [ifidget-B.Cu.gbr, ifidget-B.Mask.gbr, ifidget-B.SilkS.gbr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]
